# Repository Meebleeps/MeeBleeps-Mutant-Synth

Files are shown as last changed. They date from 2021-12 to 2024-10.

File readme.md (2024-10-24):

# Meebleeps / Wirehead Mutant Mozzi Synth

* Meebleeps was my personal project and was rebranded as Wirehead Instruments in 2023 to avoid brand confusion with MeeBlip - another completely separate synth design company.

My first Arduino project started with the plan to push lfo/envelope voltages to my Volca Modular, but thanks to inspiration from Hagiwo and the Mozzi Library it turned into a cool little generative synth that I can let run all day, built to sync & fit with my Volca collection.

https://www.youtube.com/watch?v=d2Lml1Z9uWc

Source released under Creative Commons ttribution-NonCommercial-ShareAlike 4.0

***
__Important build-note:__ my builds have used normally-closed switches, so the code assumes this.  A couple of people building this have had issues because they have normally-open switches, so to adjust for this edit the code in updateButtonControls() to invert the results of each call to digitalRead(). 
***
## Synth Voice Features

-    2 saw oscillators
-    Multiple tuning modes for 2nd oscillator - off, detune, fifths & octaves up/down
-    Digital low pass filter with variable cutoff and resonance
-    Variable level ducking/sidechain effect

## Sequencer

-    Generative sequencer mutates/evolves at user-defined rate
-    Variable sequence mutation probability & note-density
-    Variable sequencer length (1-16 steps)
-    Sync input & output (Korg Volca compatible)
-    Selectable tonic note
-    Selectable scale quantisation (Major, Minor, Pentatonic, Phrygian (GOA!), Octaves, Fifths)
-    16-step parameter-lock recording of synth parameters (the Elektron way!)
-    Retrig (clone) button for fills
-    Tap-tempo control

## Hardware

-    Arduino Nano (Elegoo)
-    Simple Mozzi output circuit
-    CV inputs (volca modular levels) for synth and sequencer parameters
-    Designed to fit into Volca form factor
-    Laser-cut metalisized acrylic faceplate
-    Laser-cut wooden box
-    9V DC Power input
-    Access to nano's USB port for firmware upgrades

## Controls

### Button Controls

| Button Index 	| Pin	| Name		| Function					| Alternative Function	|
| --- 		| --- 	| --- 		| --- 						| --- 			|
| 0		| D4	| Func		| Access alternative control function 		| n/a | 
| 1		| D5	| Start		| Starts/stops the sequencer			| Tap-tempo | 
| 2		| D6	| Scales	| Cycle through available musical scales	| Cycle through available mutation algorithms | 
| 3		| D3	| Root		| Increase the tonic note			| Decrease the tonic note | 
| 4		| D10	| Rec		| Hold to record knob movements			| Hold while moving a knob to clear the recorded value  | 
| 5		| D12	| Clone		| Retrigger the current step

### Analog Controls

| Input Index 	| Pin	| Name		| Function						| Alternative Function	|
| --- 		| --- 	| --- 		| --- 							| --- 			|
| 0		| A0	| Species		| Oscillator 2 detune					| Amount of sidechain/ducking effect	|
| 1		| A1	| Lifespan	| Note length						| n/a	|
| 2		| A2	| Mutation	| Probabilty that sequence will change over time	| Probability of a note playing on any step	|
| 3		| A3	| Shape		| Shape of the filter envelope				| n/a	|
| 4		| A4	| Colour	| Base filter value					| Filter resonance	|
| 5		| A5	| Population	| Number of steps in the sequence 1-16			| n/a	|

## Problems (mostly hardware due to this being my first project!)

-    some sort of overflow bug linked to the low pass filter which causes the unit to enter a distorted output state until the cutoff is set to zero
-    no voltage protection on inputs
-    no buffering of inputs or outputs
-    no volume control
-    probably more unknown unknowns 😂

## Thanks

-    Inspired by Hagiwo's modular builds: https://www.youtube.com/channel/UCxEr...
-    Mozzi audio library: https://sensorium.github.io/Mozzi/
-    Inkscape for vector graphics: https://inkscape.org/
-    Fritzing for circuit design: https://fritzing.org/
-    Great Scott for awesome electronics tips! https://www.youtube.com/channel/UC6mI...

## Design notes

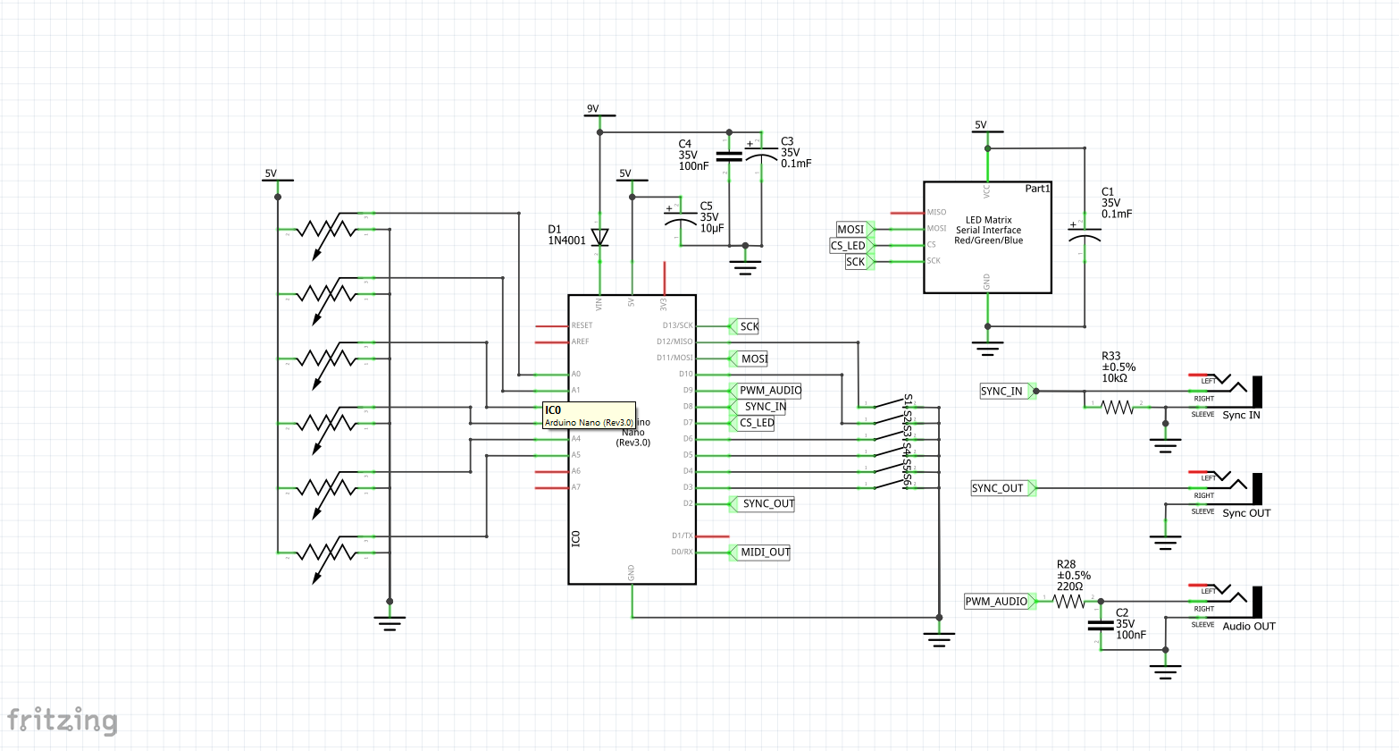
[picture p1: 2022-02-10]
MeeBleeps Mutant Schematic 09022022.png

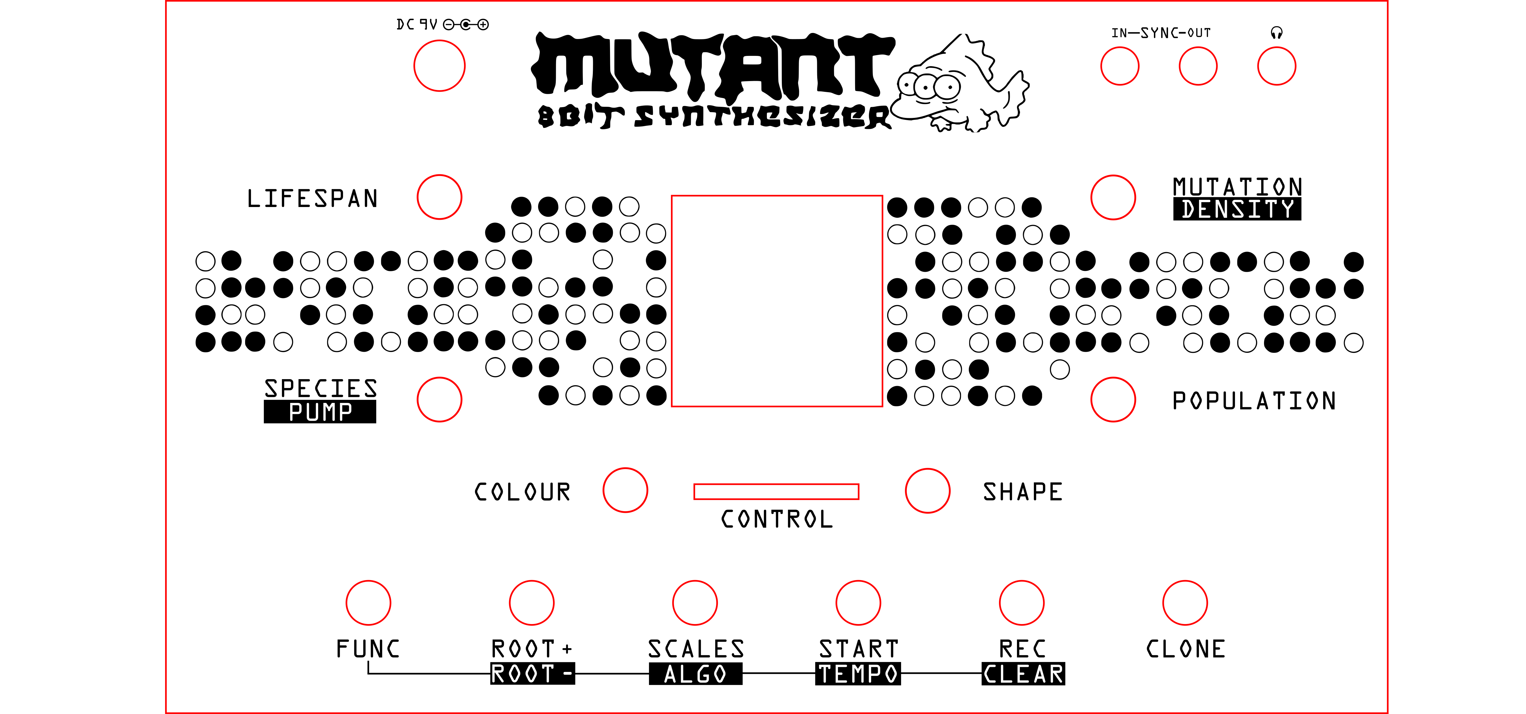
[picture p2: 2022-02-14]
mutantsynth1faceplate1.0.final.png

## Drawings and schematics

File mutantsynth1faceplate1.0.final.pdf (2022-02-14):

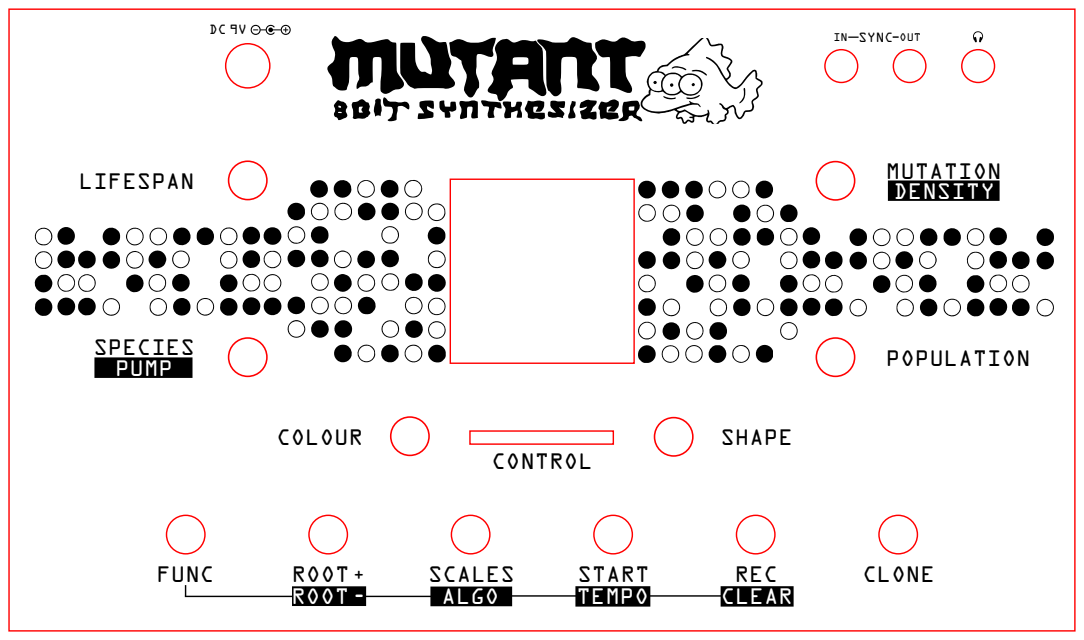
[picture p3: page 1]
FUNC; ROOT; SCALES; SHAPE; POPULATION SPECIES; START; REC; CLONE; PUMP; MUTATION DENSITY LIFESPAN; IN SYNC OUT; COLOUR; ALGO; TEMPO; CLEAR; CONTROL

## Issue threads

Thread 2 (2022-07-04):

Volca Style Controls

mayasfinest, 2022-07-04:
Hi,
thanks for sharing your project!

In the docs you write about Volca Style CV Inputs, how are they connected to the circuit? There is no reference in the schematic.
Do I have to enable them in the code? Where do these pin-sockets below the matrix go to and isn't there a ground connection i need...?

PS: I just built your Freaq Synth, love it so far, quite advanced features i'll really have to daive in...

Meebleeps, 2022-07-04:
Hi,

Another half-implemented feature, sorry! My intention was to wire them to the pot wipers similar to the way I hacked my two volcas (see demos on my YouTube channel).

But once I had finished the build, There was so much modulation with the “motion recording” that I didn’t bother to proceed with adding external modulation inputs . Like my volca mods, the theory would have been that the two devices would share a ground through a sync cable.

Cheers.
____________________

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

mayasfinest, 2022-07-04:
- Has the Clone Pushbutton any function? I wired it to D12 but there is no reference in the code...
- Can the Tempo be really, I mean really slow? The tap tempo doesn't seem to recognize my slooow taps.
- How exactly do I use the record button? I held the rec buttorn while wiggling at some pots butI don't feel it plays back any recorded movements... Do I have to be fast in any way? Can it record any pot movement? Can it record multiple pots? What happens when I "overdub", does it add a second movement. Mysterious

Tomorrow, I'll build the case (wooden) then I will show you some pics of your 2 synths (you won't recognize them ;-)
I also implanted a Volume knob from (D9 to a A100K) as I like to fade in my synths

Meebleeps, 2022-07-05:
Hi,
From memory the Clone button = retrigger in code. While pressed, It keeps the note sequencer on the current step. Idea was you can hold it down on one note for a filter build while the sequence is mutating in the background then release it to drop back to the new mutated sequence.

Not sure about the tempo, I don’t recall putting any limits in there. It is a simple time
measured between two pushes. Again this is from memory as I’m away from my account at the moment. Might be limited by variable size (eg signed int would make it max 32767ms = ~32 seconds)

Rec should record knob movements for all the synth parameters. It only records if you move the knob though, so if you don’t move it during a step it won’t record the position - you have to wiggle it (just a little bit 😂).  Moving a second time it will just store the last movement during the step.

Hope that helps. Looking forward to seeing the results!  😁

____________________

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

mayasfinest, 2022-07-05:
Greetings from Germany!

Meebleeps, 2022-10-11:
It looks so good!! Fantastic build! 👍🏻👍🏻😊😊

____________________

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

extremenerble, 2025-06-09:
> * How exactly do I use the record button? I held the rec buttorn while wiggling at some pots butI don't feel it plays back any recorded movements... Do I have to be fast in any way? Can it record any pot movement? Can it record multiple pots? What happens when I "overdub", does it add a second movement. Mysterious

I also have this issue. I've built the eurorack version from lonesurfer's instructables (https://www.instructables.com/Mutant-Generative-Arduino-Synth/). Same behavior on two Mutant module builds, the recording button doesn't actually record movements.

Recording does work on the FreaqFM (same adaptation)

I used the Arduino files from this github. All the other functions work great. Any ideas?

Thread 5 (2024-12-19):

Problems compiling in Arduino IDE

condor13, 2024-12-19:
Hello. I made your machine...but having trouble compiling it. In arduino IDE.
Instaled mozzi library (latest library) Can i get a precompiled version, or what im missing in the compiling section.

This are the last lines...

(.text+0x0): multiple definition of `audioHook()'

C:\Users\theon\AppData\Local\Temp\arduino_build_95303\sketch\MutantFMSynth.ino.cpp.o (symbol from plugin):(.text+0x0): first defined here

collect2.exe: error: ld returned 1 exit status

Using library Mozzi at version 2.0.1 in folder: C:\Users\theon\Documents\Arduino\libraries\Mozzi
Using library FixMath at version 1.0.6 in folder: C:\Users\theon\Documents\Arduino\libraries\FixMath
Using library SPI at version 1.0 in folder: C:\Users\theon\AppData\Local\Arduino15\packages\arduino\hardware\avr\1.8.6\libraries\SPI

condor13, 2024-12-19:
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
here is a picture :)

condor13, 2024-12-20:
And platform IO never used it, but installed it as you mention and it returns me:
MissingPackageManifestError: Could not find one of 'package.json' manifest files in the package

condor13, 2024-12-26:
Ok. So managed to compile this. but with a win10 machine, latest fixmath libray and 1.1.2 library for mozzi. didnt upload yet.

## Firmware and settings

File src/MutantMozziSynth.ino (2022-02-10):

/*----------------------------------------------------------------------------------------------------------
 * MutantMozziSynth.ino
 * 
 * Main project file for the Mutant Mozzi Synth. 
 * 
 * Instantiates all mutant class objects 
 * Calls the Mozzi audio hook functions
 * manages the user interface
 * 
 * was originally developed in Arduino IDE before moving to VS Code
 * 
 * (C) 2021 Meebleeps
*-----------------------------------------------------------------------------------------------------------
*/

#include <Arduino.h>
#include <MozziGuts.h>
#include <mozzi_rand.h>
#include <EventDelay.h>

#include "avSource.h"
#include "avSequencer.h"
#include "LedMatrix.h"

// MOZZI variables
#define CONTROL_RATE 256

// define the pins
#define PIN_SYNC_IN       8
#define PIN_SYNC_OUT      2
#define TIMER_SYNC_PULSE_OUTPUT_MILLIS 20

#define PIN_AUDIO_OUT     9
#define PIN_BUTTON0       4
#define PIN_BUTTON1       5
#define PIN_BUTTON2       6
#define PIN_BUTTON3       3
#define PIN_BUTTON4       10
#define PIN_BUTTON5       12
#define MAX_BUTTON_INPUTS 6


#define MAX_ANALOG_INPUTS               6
#define MAX_ANALOG_VALUE                1000

// these may change depending on how analog pots are wired up
#define ANALOG_INPUT_OSC2TUNE           0
#define ANALOG_INPUT_DECAY              1
#define ANALOG_INPUT_MUTATION           2
#define ANALOG_INPUT_FILTERSHAPE        3
#define ANALOG_INPUT_FILTER             4
#define ANALOG_INPUT_STEPCOUNT          5

// trial-and-error value to raise movement-detection above noise.  
//TODO: I'm sure there are libraries to do this!
#define ANALOG_INPUT_MOVEMENT_THRESHOLD 13

// listed in order of left to right.
#define BUTTON_INPUT_FUNC   0
#define BUTTON_INPUT_TONIC  3
#define BUTTON_INPUT_SCALE  2
#define BUTTON_INPUT_START  1
#define BUTTON_INPUT_REC    5
#define BUTTON_INPUT_RETRIG 4


//#define MAX_OSCILLATOR_MODES 1

#define INTERFACE_MODE_NORMAL 0
#define INTERFACE_MODE_SHIFT  1

// some settings persist on-screen after being changed - for this many millis
#define DISPLAY_SETTING_CHANGE_PERSIST_MILLIS 500

// motion recordind mode, depending on whether the REC button is held with/without FUNC
#define MOTION_RECORD_NONE  0
#define MOTION_RECORD_REC   1
#define MOTION_RECORD_CLEAR 2

// decrease INTERFACE_UPDATE_DIVIDER  if controls are externally modulated via CV voltage inputs
#define INTERFACE_UPDATE_DIVIDER 4

//TODO: store these in PROGMEM instead of RAM
const byte BITMAP_MEEBLEEPS[]  = {B00011000,B01111110,B11011011,B11011011,B11011011,B11011011,B11000011,B00000110};
const byte BITMAP_NUMERALS[8][8]  = {
                                       {B00000000,B00000000,B00000000,B11100000,B10100000,B10100000,B10100000,B11100111}
                                      ,{B00000000,B00000000,B00000000,B01000000,B01000000,B01000000,B01000111,B01000000}
                                      ,{B00000000,B00000000,B00000000,B11100000,B00100000,B11100111,B10000000,B11100000}
                                      ,{B00000000,B00000000,B00000000,B11100000,B00100111,B11100000,B00100000,B11100000}
                                      ,{B00000000,B00000000,B00000000,B10100111,B10100000,B11100000,B00100000,B00100000}
                                      ,{B00000000,B00000000,B00000111,B11100000,B10000000,B11100000,B00100000,B11100000}
                                      ,{B00000000,B00000111,B00000000,B11100000,B10000000,B11100000,B10100000,B11100000}
                                      ,{B00000000,B00000111,B00000000,B11100000,B00100000,B00100000,B00100000,B00100000}
                                    };
const byte BITMAP_ALPHA[7][8]  = {
                                     {B00000000,B00000000,B00000000,B11100000,B10100000,B11100000,B10100000,B10100111}
                                    ,{B00000000,B00000000,B00000000,B11100000,B10100000,B11000000,B10100111,B11100000}
                                    ,{B00000000,B00000000,B00000000,B11100000,B10000000,B10000111,B10000000,B11100000}
                                    ,{B00000000,B00000000,B00000000,B11000000,B10100111,B10100000,B10100000,B11000000}
                                    ,{B00000000,B00000000,B00000000,B11100111,B10000000,B11000000,B10000000,B11100000}
                                    ,{B00000000,B00000000,B00000111,B11100000,B10000000,B11000000,B10000000,B10000000}
                                    ,{B00000000,B00000111,B00000000,B11100000,B10000000,B10000000,B10100000,B11100000}
                                  };
const byte BITMAP_ALGORITHMS[2][8]  = {
                                        {B01000001,B10010000,B00000100,B01010000,B01000010,B01001000,B01000001,B01000100}
                                      , {B00100001,B01000010,B00000100,B11101000,B00100000,B11100001,B10000010,B11100100}
                                      };
/* old bitmaps
const byte BITMAP_NUMERALS[8][8]  = {
                                      {B00111000,B01000100,B01000100,B01000100,B01000100,B01000100,B00111000,B00000000}
                                      ,{B00010000,B00110000,B00010000,B00010000,B00010000,B00010000,B00111000,B00000000}
                                      ,{B00111000,B01000100,B00000100,B00001000,B00010000,B00100000,B01111100,B00000000}
                                      ,{B00111000,B01000100,B00000100,B00011000,B00000100,B01000100,B00111000,B00000000}
                                      ,{B00001000,B00011000,B00101000,B01001000,B01111100,B00001000,B00001000,B00000000}
                                      ,{B01111100,B01000000,B01000000,B00111000,B00000100,B00000100,B01111000,B00000000}
                                      ,{B00111100,B01000000,B01000000,B00111000,B01000100,B01000100,B00111000,B00000000}
                                      ,{B00111000,B01000100,B01000100,B00111000,B01000100,B01000100,B00111000,B00000000}
                                    };
*/

/*
const byte BITMAP_ALPHA[7][8]  = {
                                       {B00111000,B01000100,B01000100,B01111100,B01000100,B01000100,B01000100,B00000000}
                                      ,{B01111000,B01000100,B01000100,B01111000,B01000100,B01000100,B01111000,B00000000}
                                      ,{B00111000,B01000100,B01000000,B01000000,B01000000,B01000100,B00111000,B00000000}
                                      ,{B01111000,B01000100,B01000100,B01000100,B01000100,B01000100,B01111000,B00000000}
                                      ,{B01111100,B01000000,B01000000,B01111000,B01000000,B01000000,B01111100,B00000000}
                                      ,{B01111100,B01000000,B01000000,B01111000,B01000000,B01000000,B01000000,B00000000}
                                      ,{B00111000,B01000100,B01000000,B01001100,B01000100,B01000100,B00111000,B00000000}
                                    };
*/

// when user presses start for the first time, do things like seed rand generator and clear screen
byte firstTimeStart   = true;

// state of sync trigger input pin
byte iTrigger         = 1;      
byte iLastTrigger     = 0;

// state of button input pins
byte iCurrentButton[MAX_BUTTON_INPUTS];
byte iLastButton[MAX_BUTTON_INPUTS];

// state of analog input pins
int iLastAnalogValue[6]    = {0,0,0,0,0,0};
int iCurrentAnalogValue[6] = {0,0,0,0,0,0};

// used during updateControl to reduce frequency of input control updates for efficiency
byte updateCounter    = 0;

// state of interface and motion control UI modifiers
byte interfaceMode    = INTERFACE_MODE_NORMAL;
byte motionRecordMode = MOTION_RECORD_NONE;

// a bitmap setting is being displayed
byte settingDisplayIconOn = false;

//TODO: this should probably be in the sequencer
uint8_t lastStepParameterLock[6] = {false,false,false,false,false,false};

// synth voice instance
MutatingPhasor    synthVoice;

// generative sequencer instance
MutatingSequencer sequencer;

// LED matrix instance.  probably could have used a standard MAX7219 library but was easy and enjoyable to make my own :)
LedMatrix         ledDisplay;

// timer to pull sync output low at the end of the pulse 
EventDelay        syncOutputTimer;
EventDelay        settingDisplayTimer;


/*----------------------------------------------------------------------------------------------------------
 * setup()
 *----------------------------------------------------------------------------------------------------------
 */
void setup() 
{
  Serial.begin(115200);
  Serial.print(F("\n\n\n\n\n-----------------------------------------------------------------------\n"));
  Serial.print(F("Mozzi-based Mutating Techno Synth.   Build "));
  Serial.print  (__DATE__);
  Serial.print  (F(" "));
  Serial.println  (__TIME__);

  initialisePins();
  initialiseDisplay();
  initialiseSources();
  initialiseSequencer();

  startMozzi(CONTROL_RATE);
}



/*----------------------------------------------------------------------------------------------------------
 * initialiseDisplay
 *----------------------------------------------------------------------------------------------------------
 */
void initialiseDisplay()
{
  ledDisplay.initialise();
  ledDisplay.setOrientation(LEDMATRIX_ORIENTATION_0);
  
  settingDisplayTimer.start(0);
  settingDisplayIconOn = false;

  // display logo intro
  for (int i=10; i< 100; i+=10)
  {
    ledDisplay.clearScreen();
    delay(i);
    ledDisplay.displayIcon(BITMAP_MEEBLEEPS);
    delay(i);
  }
  
  // fade
  for(int i = 15; i>= 0; i--)
  {
    ledDisplay.setIntensity(i);
    delay(20);
  }

  // set default brightness to 4 for normal use
  ledDisplay.setIntensity(4);
  ledDisplay.displayIcon(BITMAP_MEEBLEEPS);
}




/*----------------------------------------------------------------------------------------------------------
 * initialisePins
 *----------------------------------------------------------------------------------------------------------
 */
void initialisePins()
{
  Serial.println(F("initialisePins()"));


  pinMode(PIN_SYNC_OUT, OUTPUT);
  pinMode(PIN_SYNC_IN, INPUT);          // sync is pulled down by external pulldown resistor
  pinMode(PIN_BUTTON0, INPUT_PULLUP);   // all other buttons are pulled up by internal pullup resistor
  pinMode(PIN_BUTTON1, INPUT_PULLUP);
  pinMode(PIN_BUTTON2, INPUT_PULLUP);
  pinMode(PIN_BUTTON3, INPUT_PULLUP);
  pinMode(PIN_BUTTON4, INPUT_PULLUP);
  pinMode(PIN_BUTTON5, INPUT_PULLUP);

  pinMode(A0, INPUT);
  pinMode(A1, INPUT);
  pinMode(A2, INPUT);
  pinMode(A3, INPUT);
  pinMode(A4, INPUT);
  pinMode(A5, INPUT); 

  // initialise button state arrays
  for (int i = 0; i < MAX_BUTTON_INPUTS; i++)
  {
    iLastButton[i]    = 0;
    iCurrentButton[i] = 0;
  }

  for (int i = 0; i < MAX_ANALOG_INPUTS; i++)
  {
    iLastAnalogValue[i] = 0;
  }
}



/*----------------------------------------------------------------------------------------------------------
 * initialiseSources
 * Do anything necessary to initialise the synth voice/s that wasn't done in the constructor
 *----------------------------------------------------------------------------------------------------------
 */
void initialiseSources()
{
  
  //TODO: anything necessary to initialise the synth voice/s that wasn't done in the constructor
  
}



/*----------------------------------------------------------------------------------------------------------
 * initialiseSequencer
 * set the scalemode to minor and creates a new sequence
 *----------------------------------------------------------------------------------------------------------
 */
void initialiseSequencer()
{
  sequencer.setScale(SCALEMODE_MINOR);
  sequencer.newSequence(16);
}




/*----------------------------------------------------------------------------------------------------------
 * updateControl
 * called by Mozzi Library on CONTROL_RATE frequency
 * every INTERFACE_UPDATE_DIVIDER steps, check controls
 * every step - check for sync trigger and update sequencer
 * if this gets delayed, note on/off commands will drift
 *----------------------------------------------------------------------------------------------------------
 */
void updateControl()
{
  updateCounter++;

  // do this every time to ensure sync
  updateSyncTrigger();

  // check controls once every INTERFACE_UPDATE_DIVIDER steps for efficiency
  // todo:  decrease INTERFACE_UPDATE_DIVIDER  if these are externally modulated via CV voltage inputs
  if(updateCounter % INTERFACE_UPDATE_DIVIDER == 0)
  {

    // check button controls first to ensure interface mode is correctly set
    updateButtonControls();

    // now check analog controls
    updateAnalogControls();
  }

  // update sequencer every time to minimise latency
  // returns true if the seqeuncer has moved to next step
  if (updateSequencer())
  {
     //only update the display once per sequencer step    
     //TODO: this could be increased for more responsive display
    updateDisplay();
  }
  
  // check to see if the output sync pulse needs to be pulled low
  if (syncOutputTimer.ready())
  {
    digitalWrite(PIN_SYNC_OUT, LOW);
  }

  
  // now that all controls are updated, update the source.
  
  
  // sequencer sets the ducking amount based on internal envelope
  long duckingAmount = sequencer.getDuckingAmount();
  
  
  if (duckingAmount > 0)
  {
    long duckingGain;

    duckingGain = sequencer.getDuckingEnvelope();

    if (duckingGain < 250)
    {
      duckingGain = ((duckingGain*duckingAmount) >> 8) + (256-duckingAmount);
      
      // display the ducking gain reduction as a bar on the LED matrix
      ledDisplay.drawLineV(6, 0, 6,true);
      ledDisplay.drawLineV(6, 0, scaleAnalogInput( duckingGain*4,6),false);
    }
    else
    {
      duckingGain = 255;
    }
    
    synthVoice.setGain(duckingGain);
  }
  else
  {
    synthVoice.setGain(255);
  }

  synthVoice.updateControl();
}


/*----------------------------------------------------------------------------------------------------------
 * updateSequencer
 * returns true if sequencer advances to the next step
 *----------------------------------------------------------------------------------------------------------
 */
int updateSequencer()
{
  byte      nextNote;
  uint16_t  nextNoteLength;
  
  // if the sequencer is due to make a new step, 
  if (sequencer.update(false))
  {
    // if the sequencer is on an even step - output a sync pulse
    if (sequencer.outputSyncPulse())
    {
      outputSyncPulse();
    }
    
    nextNote        = sequencer.getCurrentNote();
    nextNoteLength  = sequencer.getNextNoteLength();
    
    if (nextNote > 0)
    {
      updateSequencerStepModulation();

      synthVoice.noteOn(nextNote, 255, nextNoteLength);
    }
    
    return true;
  }
  else
  {
    return false;
  }

  
}


/*----------------------------------------------------------------------------------------------------------
 * outputSyncPulse
 * sends a digital signal to the output pin and sets the timer to pull it low after TIMER_SYNC_PULSE_OUTPUT_MILLIS
 *----------------------------------------------------------------------------------------------------------
 */
void outputSyncPulse()
{
  syncOutputTimer.start(TIMER_SYNC_PULSE_OUTPUT_MILLIS);
  digitalWrite(PIN_SYNC_OUT,  HIGH);
}


/*----------------------------------------------------------------------------------------------------------
 * updateSequencerModulation
 * updates source parameters based on current control values or recorded motion (if any) 
 *----------------------------------------------------------------------------------------------------------
 */
void updateSequencerStepModulation()
{
 
  if (sequencer.getParameterLock(0) != 0)
  {
    sequencer.setNextNoteLength(sequencer.getParameterLock(0));
    lastStepParameterLock[0] = true;
  }
  else if (lastStepParameterLock[0])  // if the last step was parameter locked, then reset to the current knob position
  {
    updateNoteDecay(true);
    lastStepParameterLock[0] = false;
  }

  if (sequencer.getParameterLock(1) != 0)
  {
    synthVoice.setOscillatorDetune(sequencer.getParameterLock(1));
    lastStepParameterLock[1] = true;
  }
  else if (lastStepParameterLock[1])  // if the last step was parameter locked, then reset to the current knob position
  {
    updateOscillatorDetune(true);
    lastStepParameterLock[1] = false;
  }

  if (sequencer.getParameterLock(2) != 0)
  {
    synthVoice.setFilterCutoff(sequencer.getParameterLock(2));
    lastStepParameterLock[2] = true;
  }
  else if (lastStepParameterLock[2])  // if the last step was parameter locked, then reset to the current knob position
  {
    updateFilterCutoff(true);
    lastStepParameterLock[1] = false;
  }

  if (sequencer.getParameterLock(3) != 0)
  {
    synthVoice.setFilterResonance(sequencer.getParameterLock(3));
    lastStepParameterLock[3] = true;
  }
  else if (lastStepParameterLock[3])  // if the last step was parameter locked, then reset to the current knob position
  {
    updateFilterResonance(true);
    lastStepParameterLock[3] = false;
  }

  if (sequencer.getParameterLock(4) != 0)
  {
    synthVoice.setFilterShape(sequencer.getParameterLock(4));
    lastStepParameterLock[4] = true;    
  }
  else if (lastStepParameterLock[4])  // if the last step was parameter locked, then reset to the current knob position
  {
    updateFilterShape(true);
    lastStepParameterLock[4] = false;
  }
}




/*----------------------------------------------------------------------------------------------------------
 * updateSyncTrigger
 * check for sync trigger and update sequencer
 *----------------------------------------------------------------------------------------------------------
 */
void updateSyncTrigger()
{
  iTrigger = digitalRead(PIN_SYNC_IN);   // read the sync pin

  if (iTrigger != iLastTrigger)
  {
    digitalWrite(PIN_SYNC_OUT, iTrigger);
    
    //trigger note on or off
    if (iTrigger == HIGH)
    {
      //Serial.println("sync!");
      sequencer.syncPulse(SYNC_STEPS_PER_PULSE);
    }

    iLastTrigger = iTrigger;
  }
}
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
void loop() 
{
  //required for Mozzi
  audioHook();
}

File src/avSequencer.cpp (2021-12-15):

/*----------------------------------------------------------------------------------------------------------
 * avSequencer.cpp
 * 
 * Implements a generative sequencer with multiple generative algorithms, musical scale quantisation,
 * variable sequence length (up to 16 steps) and multiple parameter-lock (motion-sequencing) channels
 * 
 * (C) 2021 Meebleeps
*-----------------------------------------------------------------------------------------------------------
*/
#include <mozzi_rand.h>
#include <MozziGuts.h>

#include "Arduino.h"
#include "avSequencer.h"

/*----------------------------------------------------------------------------------------------------------
 * MutatingSequencer::MutatingSequencer()
 * initialises the sequencer
 *----------------------------------------------------------------------------------------------------------
 */
MutatingSequencer::MutatingSequencer()
{
  running             = false;
  mutationAlgorithm   = MUTATE_ALGO_DEFAULT;

  // initialise sequence
  for (int i = 0; i < MAX_SEQUENCE_LENGTH; i++)
  {
    notes[i] = 0;
  }
  
  for (int i = 0; i < MAX_SCALE_LENGTH; i++)
  {
    scaleNotes[i] = 0;
  }

  for (int i = 0; i < MAX_SEQUENCE_LENGTH; i++)
  {
    for (int m = 0; m < 6; m++)
    {
      parameterLocks[m][i] = 0;
    }
  }

  currentStep         = 0;  
  retrigStep          = 0;     
  retrigState         = false;                        
  tonicNote           = 33;   // default to A2                           
  mutationProbability = 0;
  noteProbability      = 70;
  tonicProbability    = 30;
  rachetProbability   = 30;
  scatterProbability  = 0;
  shufflePct          = 50;
  sequenceLength      = 16;
  bpm                 = 130;
  currentNote         = tonicNote;
  nextStepNoteLength  = 80;
  octaveSpread        = 3;  
  scaleNoteCount      = 7;

  // deleted this to allow for different pulse steps defined by the UI layer
  //syncPulseSteps        = 2;      // standard 2 steps per sync pulse as per volca
  syncPulseClockDivide  = 1;      // divide the clock by this many steps
  
  nextStepTimeMillis  = (15000 / bpm); // 16th note length for given BPM
  
  lastSyncPulseTimeMicros = 0;
  
  initialiseScale(SCALEMODE_PENTA);
  newSequence(sequenceLength);

  duckingEnvelope.setTimes(80,1000,1000,5);
  duckingEnvelope.setADLevels(0,255);
  duckingCounter = 0;

  _debugOutput        = true;
  printParameters();
}



/*----------------------------------------------------------------------------------------------------------
 * MutatingSequencer::start()
 * starts the sequencer at step 0
 *----------------------------------------------------------------------------------------------------------
 */
void MutatingSequencer::start()
{
  Serial.println(F("Sequencer.Start()"));
  running             = true;
  ignoreNextSyncPulse = true;
  //nextStep(true);
}




/*----------------------------------------------------------------------------------------------------------
 * MutatingSequencer::stop()
 * stops the sequencer
 *----------------------------------------------------------------------------------------------------------
 */
void MutatingSequencer::stop()
{
  Serial.println(F("Sequencer.Stop()"));

  running = false;
}


/*----------------------------------------------------------------------------------------------------------
 * MutatingSequencer::toggleStart()
 * starts the sequencer if it is stopped, otherwise stops it
 *----------------------------------------------------------------------------------------------------------
 */
void MutatingSequencer::toggleStart()
{
  if (!running)
  {
    start();
  }
  else
  {
    stop();  
  }
}



/*----------------------------------------------------------------------------------------------------------
 * MutatingSequencer::setScale()
 * sets the scale and generates a new sequence according to the new scale
 *----------------------------------------------------------------------------------------------------------
 */
 void MutatingSequencer::setScale(uint8_t scaleMode)
{
  initialiseScale(scaleMode);
  newSequence(sequenceLength);
  Serial.print("NEW SCALE: ");
  Serial.println(scaleMode);
}


/*----------------------------------------------------------------------------------------------------------
 * MutatingSequencer::getScale()
 * returns the current scale mode
 *----------------------------------------------------------------------------------------------------------
 */
 uint8_t MutatingSequencer::getScale()
{
  return currentScaleMode;
}


/*----------------------------------------------------------------------------------------------------------
 * MutatingSequencer::getAlgorithm()
 * returns the current mutation algorithm
 *----------------------------------------------------------------------------------------------------------
 */
uint8_t MutatingSequencer::getAlgorithm()
{
  return mutationAlgorithm;
}


/*----------------------------------------------------------------------------------------------------------
 * MutatingSequencer::setAlgorithm()
 * sets the current mutation algorithm
 *----------------------------------------------------------------------------------------------------------
 */
void MutatingSequencer::setAlgorithm(uint8_t newValue)
{
  mutationAlgorithm = newValue % MAX_MUTATE_ALGO_COUNT;
}

/*----------------------------------------------------------------------------------------------------------
 * MutatingSequencer::incrAlgorithm()
 * moves to the next algorithm
 *----------------------------------------------------------------------------------------------------------
 */
void MutatingSequencer::nextAlgorithm()
{
  mutationAlgorithm = (mutationAlgorithm + 1) % MAX_MUTATE_ALGO_COUNT;
  Serial.print(F("New Algorithm = "));
  Serial.println(mutationAlgorithm);
}




/*----------------------------------------------------------------------------------------------------------
 * MutatingSequencer::getCurrentNote()
 * gets the note value for the current step
 *----------------------------------------------------------------------------------------------------------
 */
byte MutatingSequencer::getCurrentNote()
{
  if (!retrigState)
  {
    return notes[currentStep];
  }
  else
  {
    return notes[retrigStep];
  }
}


/*----------------------------------------------------------------------------------------------------------
 * MutatingSequencer::getCurrentStep()
 * gets  the current playing step
 *----------------------------------------------------------------------------------------------------------
 */
byte MutatingSequencer::getCurrentStep()
{
  if(!retrigState)
  {
    return currentStep;
  }
  else
  {
    return retrigStep;
  }
  
}
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

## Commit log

2021-12-15 Minor code cleanup & bugfix
    [MutantMozziSynth.ino, avSequencer.cpp, avSequencer.h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]
2022-02-09 Added updated schematics
    [MeeBleeps Mutant Schematic 09022022.fzz]
2022-02-10 Added note re normally-closed switches
2022-02-10 Added support for normally-open switches
2024-10-24 Updated to clarify Wirehead/Meebleeps/Meeblip
